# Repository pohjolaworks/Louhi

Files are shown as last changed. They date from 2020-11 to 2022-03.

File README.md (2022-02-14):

## Louhi

Louhi is a DIY 50% mechanical keyboard PCB, with an ortho layout. It is meant to be fairly easy to solder and assemble.

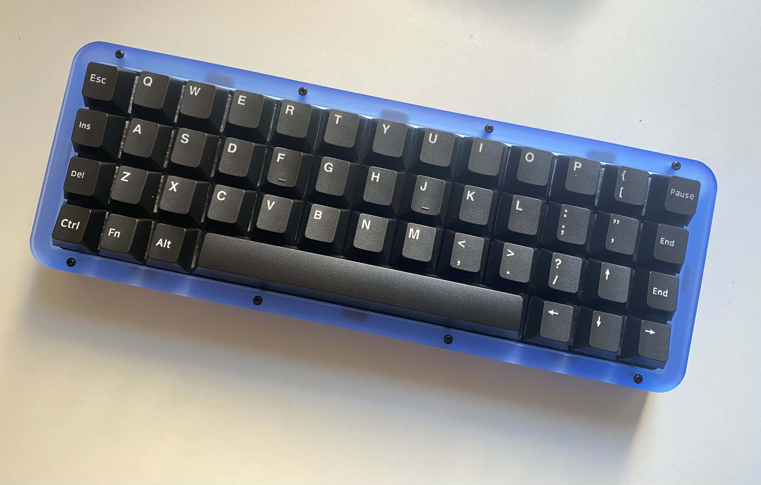
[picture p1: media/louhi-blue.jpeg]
  


Specs:

    Uses a Pro Micro, Elite-C or Proton-C (or any other controller with same form factor)
    Cherry MX Switches, PCB or plate-mount
    Support for multiple bottom layouts
    Uses one pcb-mount stabilizer
    QMK and Vial Compatible

## Supported layouts
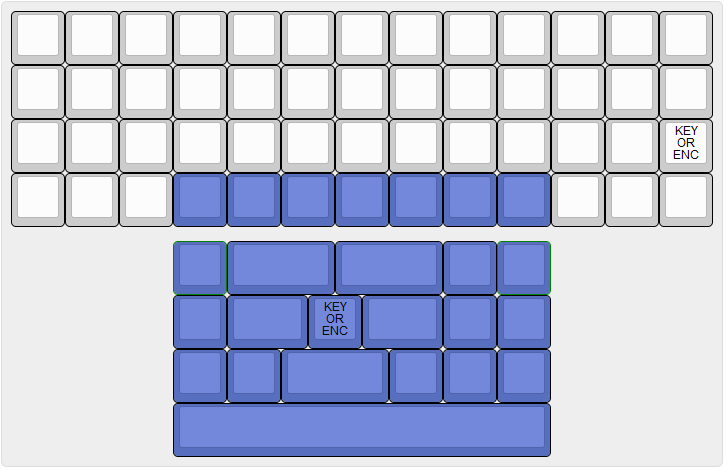
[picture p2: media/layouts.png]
  
## Plate
Gasket-mount universal plate files are located in the FR4-Plate folder. Uses 0.75mm thick gasket material on both sides of the plate.

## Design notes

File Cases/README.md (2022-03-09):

# Cases

These are case files for stacked acrylic cases, meant to work with the FR4-Plate files.

The standard, straight-edged acrylic case has WKL and HHKB top variants, where as the curvy does not.

Assembly is done using M2 knurled standoffs and M2 screws. The height of these parts will be dependent on
your build's thickness, which can be varied with the amount of acrylic layers.

I've personally used M2x10 and M2x5 screws, with 14mm tall M2 knurled standoffs with the straight-edge files
using no riser feet.

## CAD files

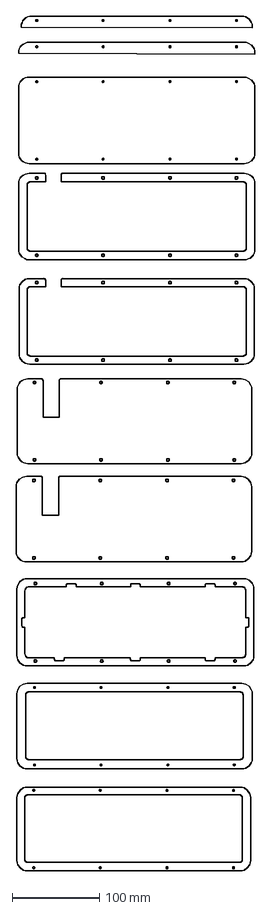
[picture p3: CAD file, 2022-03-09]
Cases/stacked_acrylic_curvy/Louhi stacked acrylic curvy all parts.dxf
273.3 x 978.8 mm

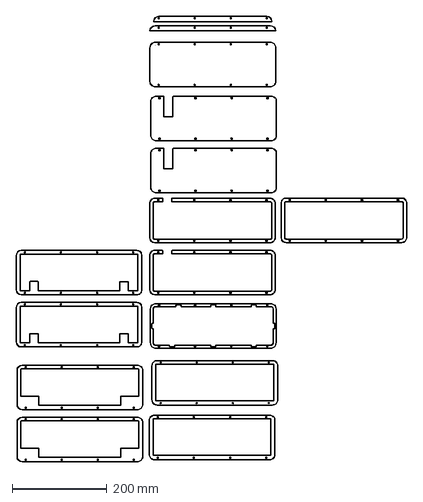
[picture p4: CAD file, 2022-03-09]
Cases/stacked_acrylic_straight/Louhi straight all parts.dxf
825.2 x 941.3 mm

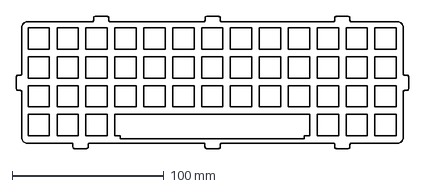
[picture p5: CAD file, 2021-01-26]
FR4-plate/Louhi-FR4-plate.dxf
258.5 x 87.0 mm

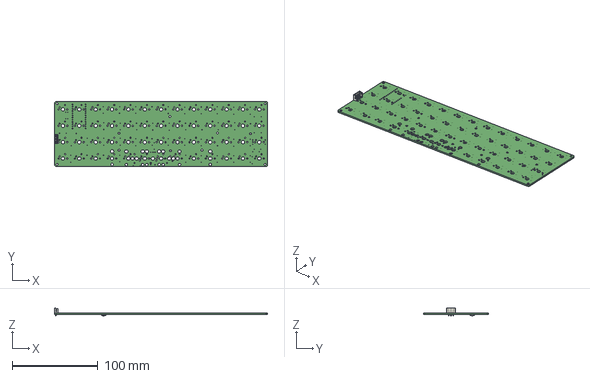
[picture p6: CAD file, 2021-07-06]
Louhi.step
247.9 x 76.2 x 9.24 mm

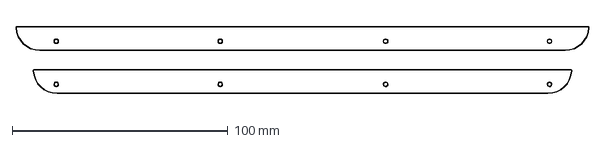
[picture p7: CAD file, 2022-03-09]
Cases/stacked_acrylic_straight/Riser feet.dxf
265.5 x 31.0 mm

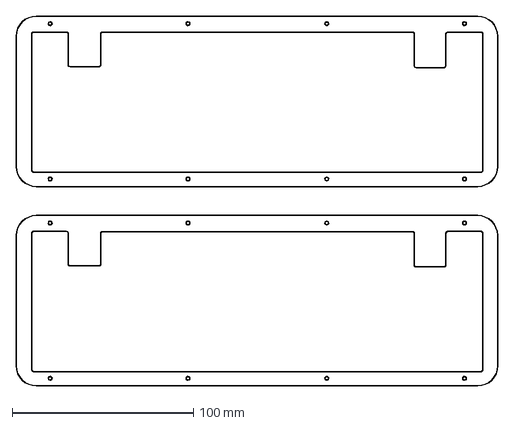
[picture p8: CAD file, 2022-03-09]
Cases/stacked_acrylic_straight/WKL Top parts.dxf
265.5 x 204.0 mm

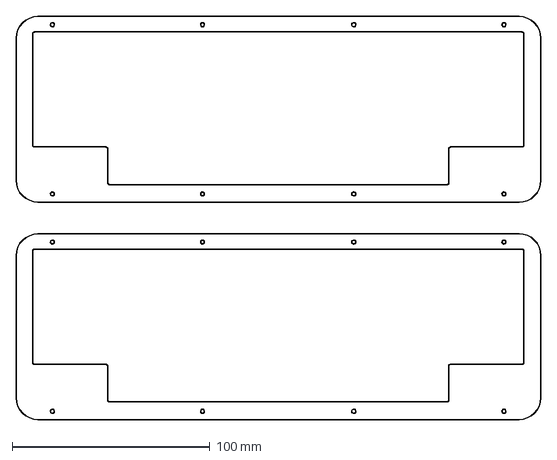
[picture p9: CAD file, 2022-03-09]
Cases/stacked_acrylic_straight/HHKB Top parts.dxf
265.5 x 204.0 mm

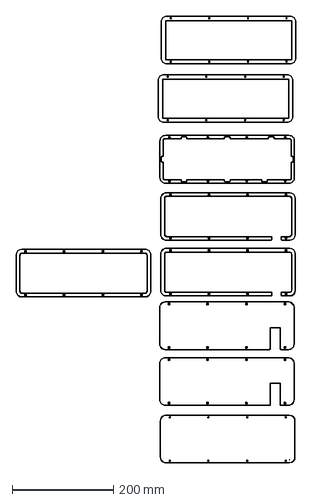
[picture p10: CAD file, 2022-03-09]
Cases/stacked_acrylic_straight/Standard case parts.dxf
551.7 x 881.9 mm

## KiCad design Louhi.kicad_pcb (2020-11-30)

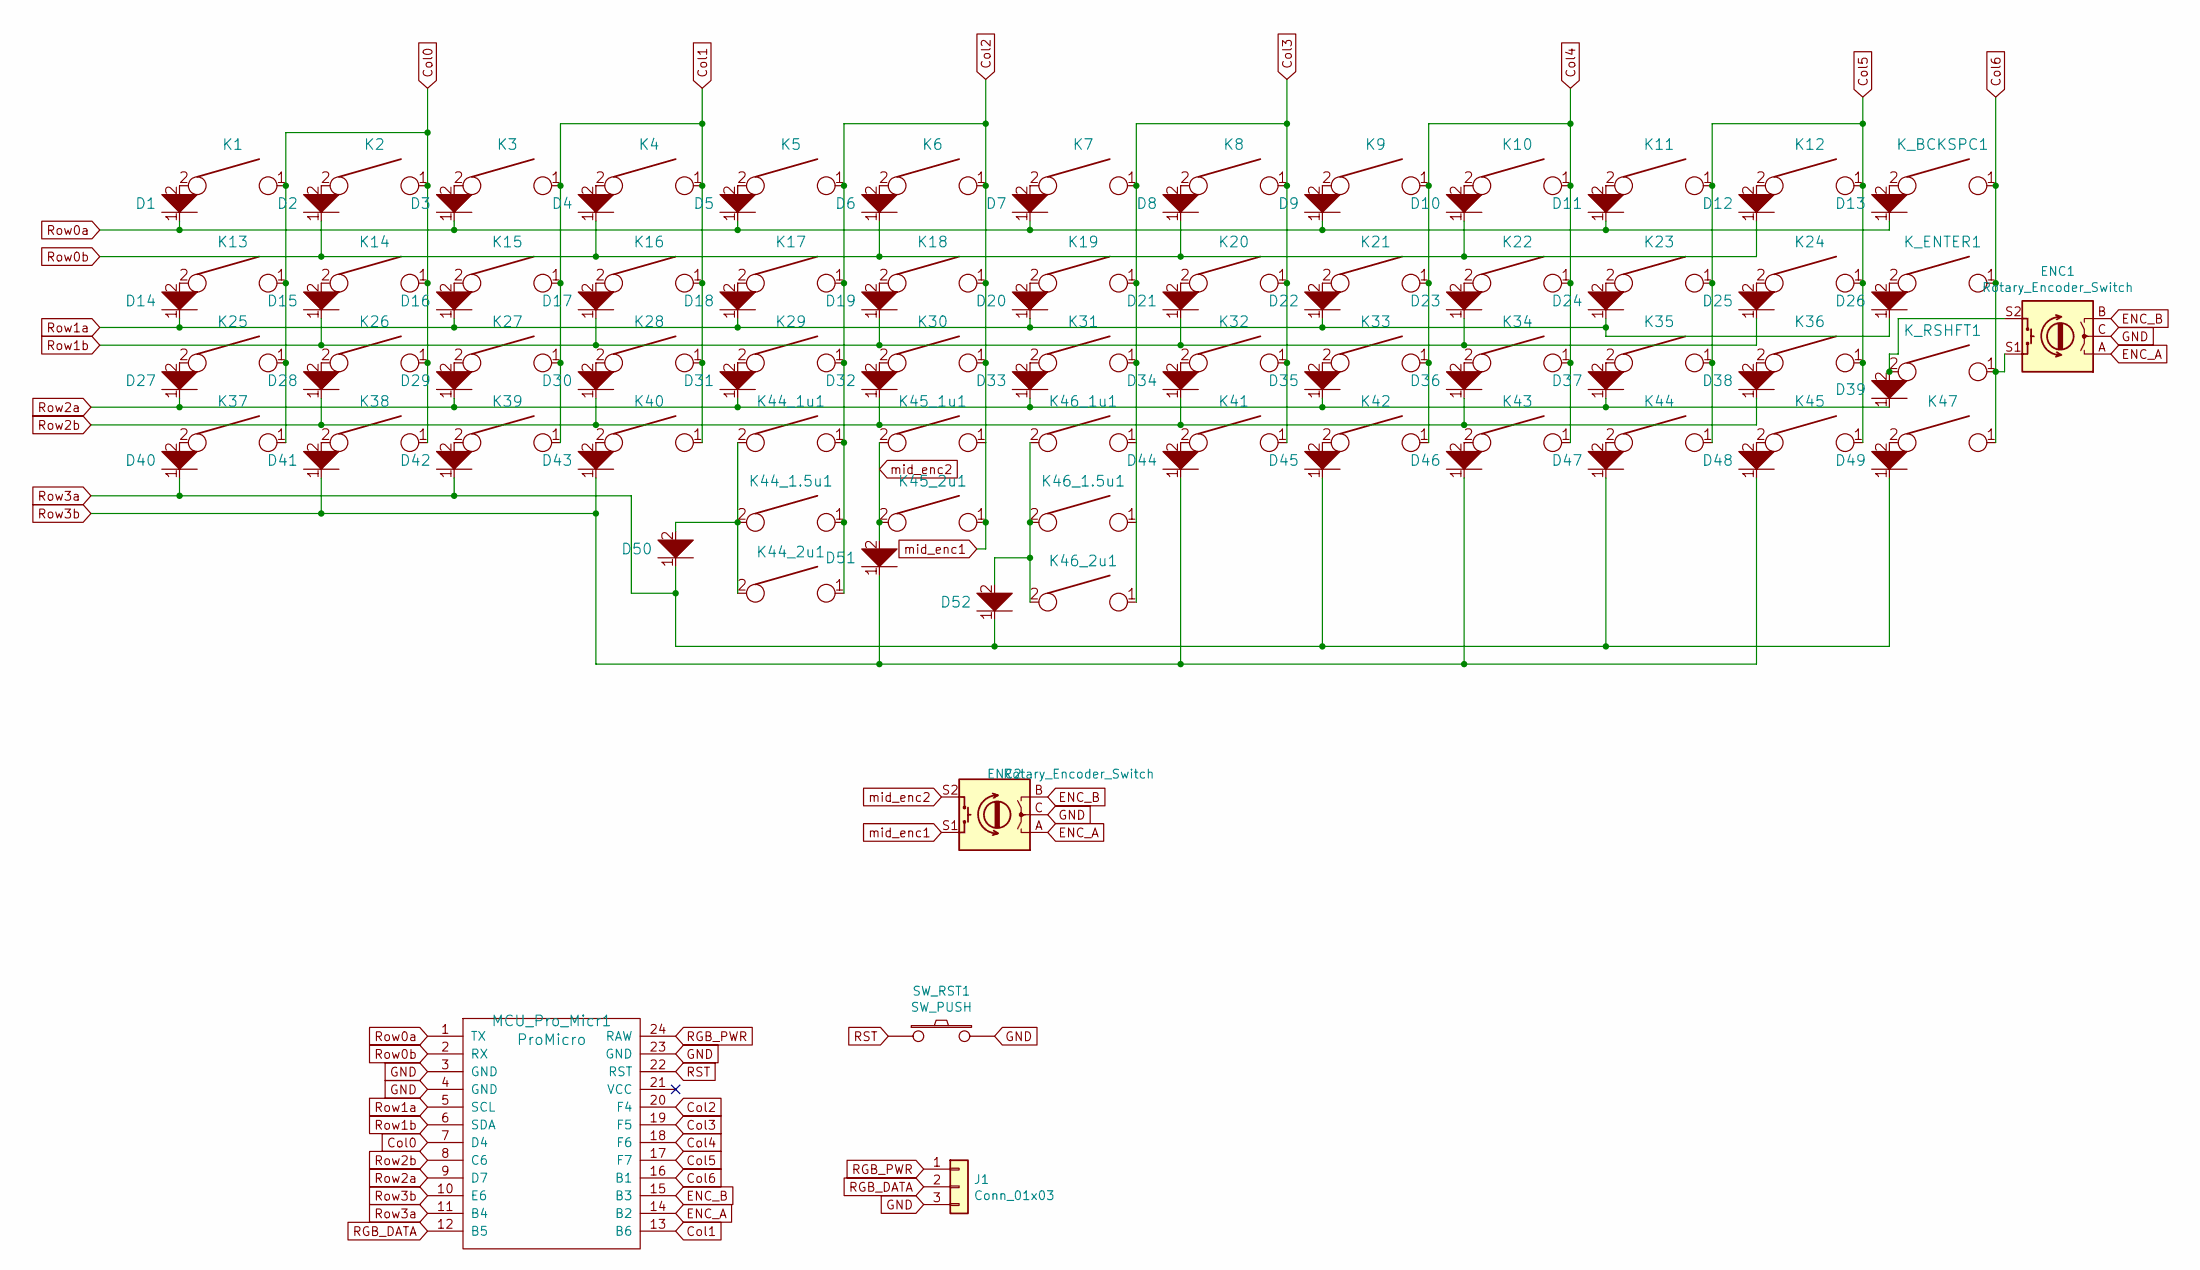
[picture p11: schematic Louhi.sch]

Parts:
D1, D2, D3, D4, D5, D6, D7, D8, D9, D10, D11, D12, D13, D14, D15, D16, D17, D18, D19, D20, D21, D22, D23, D24, D25, D26, D27, D28, D29, D30, D31, D32, D33, D34, D35, D36, D37, D38, D39, D40, D41, D42, D43, D44, D45, D46, D47, D48, D49, D50, D51, D52: D; D_SOD123_axial
ENC1, ENC2: Rotary_Encoder_Switch; RotaryEncoder_EC11-no-legs
J1: Conn_01x03; 3_Pin_Jumper
K1, K2, K3, K4, K5, K6, K7, K8, K9, K10, K11, K12, K13, K14, K15, K16, K17, K18, K19, K20, K21, K22, K23, K24, K25, K26, K27, K28, K29, K30, K31, K32, K33, K34, K35, K36, K37, K38, K39, K40, K41, K42, K43, K44, K44_1u1, K45, K45_1u1, K46_1u1, K47: KEYSW; SW_Cherry_MX_1.00u_PCB
K44_1.5u1, K46_1.5u1: KEYSW; SW_Cherry_MX_1.50u_PCB
K44_2u1, K45_2u1, K46_2u1: KEYSW; SW_Cherry_MX_2.00u_PCB
K_BCKSPC1: KEYSW; SW_Cherry_MX_1.00u_PCB
K_ENTER1: KEYSW; SW_Cherry_MX_1.00u_PCB
K_RSHFT1: KEYSW; SW_Cherry_MX_1.00u_PCB
MCU_Pro_Micr1: ProMicro; ArduinoProMicro-BackSide
SW_RST1: SW_PUSH; SW_SPST_TL3342

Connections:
Col0: K1.1, K2.1, K13.1, K14.1, K25.1, K26.1, K37.1, K38.1, MCU_Pro_Micr1.7 (D4)
Col1: K3.1, K4.1, K15.1, K16.1, K27.1, K28.1, K39.1, K40.1, MCU_Pro_Micr1.13 (B6)
Col2: ENC2.S1, K5.1, K6.1, K17.1, K18.1, K29.1, K30.1, K44_1.5u1.1, K44_1u1.1, K44_2u1.1, K45_1u1.1, K45_2u1.1, MCU_Pro_Micr1.20 (F4)
Col3: K7.1, K8.1, K19.1, K20.1, K31.1, K32.1, K41.1, K46_1.5u1.1, K46_1u1.1, K46_2u1.1, MCU_Pro_Micr1.19 (F5)
Col4: K9.1, K10.1, K21.1, K22.1, K33.1, K34.1, K42.1, K43.1, MCU_Pro_Micr1.18 (F6)
Col5: K11.1, K12.1, K23.1, K24.1, K35.1, K36.1, K44.1, K45.1, MCU_Pro_Micr1.17 (F7)
Col6: ENC1.S1, K47.1, K_BCKSPC1.1, K_ENTER1.1, K_RSHFT1.1, MCU_Pro_Micr1.16 (B1)
ENC_A: ENC1.A, ENC2.A, MCU_Pro_Micr1.14 (B2)
ENC_B: ENC1.B, ENC2.B, MCU_Pro_Micr1.15 (B3)
GND: ENC1.C, ENC2.C, J1.3, MCU_Pro_Micr1.3 (GND), MCU_Pro_Micr1.4 (GND), MCU_Pro_Micr1.23 (GND), SW_RST1.2
unnamed: D1.2, K1.2
unnamed: D2.2, K2.2
unnamed: D3.2, K3.2
unnamed: D4.2, K4.2
unnamed: D5.2, K5.2
unnamed: D6.2, K6.2
unnamed: D7.2, K7.2
unnamed: D8.2, K8.2
unnamed: D9.2, K9.2
unnamed: D10.2, K10.2
unnamed: D11.2, K11.2
unnamed: D12.2, K12.2
unnamed: D13.2, K_BCKSPC1.2
unnamed: D14.2, K13.2
unnamed: D15.2, K14.2
unnamed: D16.2, K15.2
unnamed: D17.2, K16.2
unnamed: D18.2, K17.2
unnamed: D19.2, K18.2
unnamed: D20.2, K19.2
unnamed: D21.2, K20.2
unnamed: D22.2, K21.2
unnamed: D23.2, K22.2
unnamed: D24.2, K23.2
unnamed: D25.2, K24.2
unnamed: D26.2, K_ENTER1.2
unnamed: D27.2, K25.2
unnamed: D28.2, K26.2
unnamed: D29.2, K27.2
unnamed: D30.2, K28.2
unnamed: D31.2, K29.2
unnamed: D32.2, K30.2
unnamed: D33.2, K31.2
unnamed: D34.2, K32.2
unnamed: D35.2, K33.2
unnamed: D36.2, K34.2
unnamed: D37.2, K35.2
unnamed: D38.2, K36.2
unnamed: D39.2, ENC1.S2, K_RSHFT1.2
unnamed: D40.2, K37.2
unnamed: D41.2, K38.2
unnamed: D42.2, K39.2
unnamed: D43.2, K40.2
unnamed: D44.2, K41.2
unnamed: D45.2, K42.2
unnamed: D46.2, K43.2
unnamed: D47.2, K44.2
unnamed: D48.2, K45.2
unnamed: D49.2, K47.2
unnamed: D50.2, K44_1.5u1.2, K44_1u1.2, K44_2u1.2
unnamed: D52.2, K46_1.5u1.2, K46_1u1.2, K46_2u1.2
RGB_DATA: J1.2, MCU_Pro_Micr1.12 (B5)
RGB_PWR: J1.1, MCU_Pro_Micr1.24 (RAW)
RST: MCU_Pro_Micr1.22 (RST), SW_RST1.1
Row0a: D1.1, D3.1, D5.1, D7.1, D9.1, D11.1, D13.1, MCU_Pro_Micr1.1 (TX)
Row0b: D2.1, D4.1, D6.1, D8.1, D10.1, D12.1, MCU_Pro_Micr1.2 (RX)
Row1a: D14.1, D16.1, D18.1, D20.1, D22.1, D24.1, D26.1, MCU_Pro_Micr1.5 (SCL)
Row1b: D15.1, D17.1, D19.1, D21.1, D23.1, D25.1, MCU_Pro_Micr1.6 (SDA)
Row2a: D27.1, D29.1, D31.1, D33.1, D35.1, D37.1, D39.1, MCU_Pro_Micr1.9 (D7)
Row2b: D28.1, D30.1, D32.1, D34.1, D36.1, D38.1, MCU_Pro_Micr1.8 (C6)
Row3a: D40.1, D42.1, D45.1, D47.1, D49.1, D50.1, D52.1, MCU_Pro_Micr1.11 (B4)
Row3b: D41.1, D43.1, D44.1, D46.1, D48.1, D51.1, MCU_Pro_Micr1.10 (E6)
mid_enc2: D51.2, ENC2.S2, K45_1u1.2, K45_2u1.2

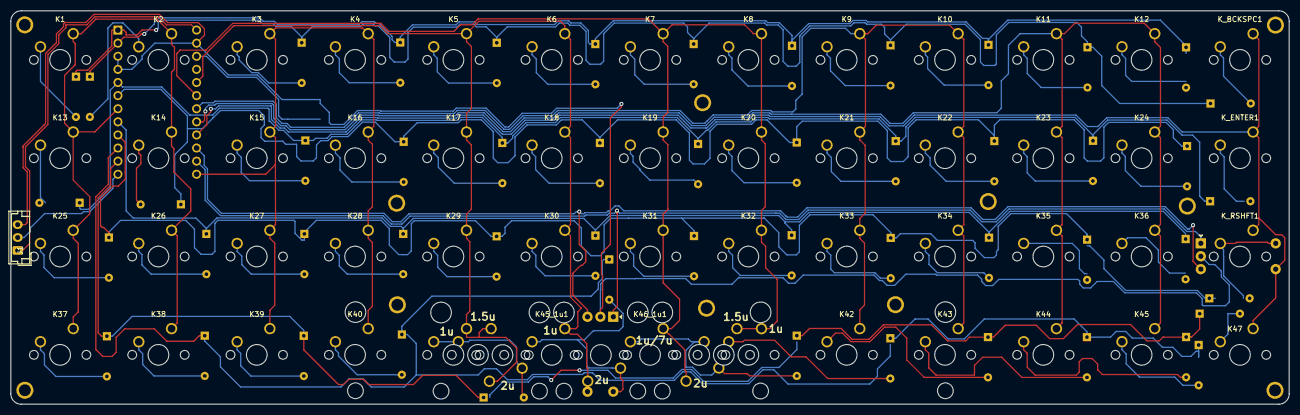
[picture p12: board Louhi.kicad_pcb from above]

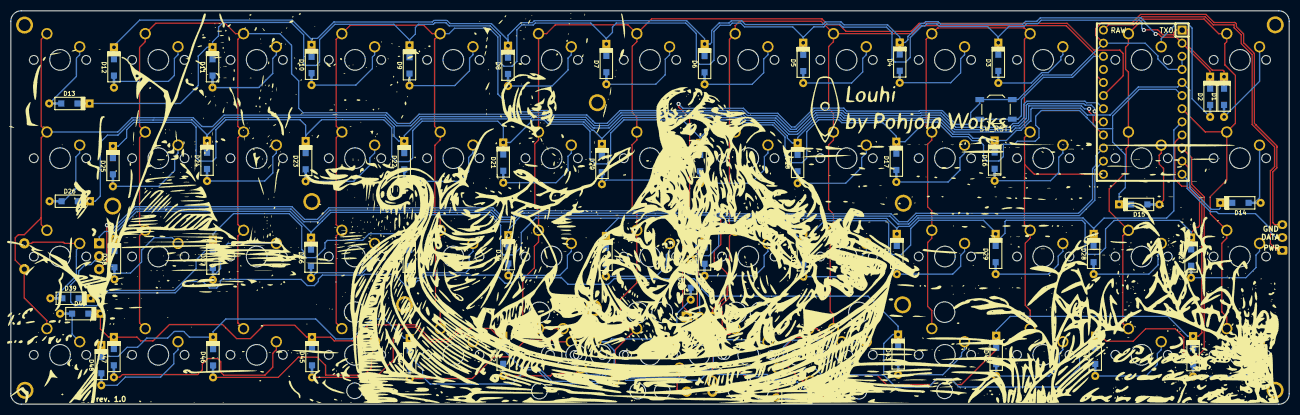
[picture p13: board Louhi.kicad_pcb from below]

Board: 2 copper layers, 247.7 x 76.2 mm, 125 parts (53 on the bottom side), 73 nets.

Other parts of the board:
HOLE5, HOLE5#2, HOLE5#3, HOLE5#4, HOLE5#5, HOLE5#6, HOLE5#7, HOLE5#8, HOLE5#9, HOLE5#10, HOLE5#11: MountingHole_4mm; MountingHole_M2

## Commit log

2020-11-30 Initial push
    [Louhi-B_CrtYd.gbr, Louhi-B_Cu.gbl, Louhi-B_Mask.gbs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]
2021-01-26 Add FR4 gasket plate
    [Louhi-FR4-plate-B_Cu.gbl, Louhi-FR4-plate-B_Mask.gbs, Louhi-FR4-plate-B_Paste.gbp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]
2021-07-06 Add images and STEP file
    [Louhi.step]
2022-03-09 First versions of stacked acrylic cases
    [HHKB Top parts.dxf, Louhi stacked acrylic curvy all parts.dxf, Louhi straight all parts.dxf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]
